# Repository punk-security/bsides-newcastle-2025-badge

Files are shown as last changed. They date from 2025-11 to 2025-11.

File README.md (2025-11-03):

# bsides-newcastle-2025-badge
The space badge for BSIDES Newcastle 2025!

This badge is a bit like our other ones, such as Cheltenham 2024 which was also a morse code game.

For this one, we printed some signs out with the codes for the players and stuck them around the venue. We really wanted to do a more art focused badge, so we didnt try any new technical gimmicks. The satellite you see on the badge was traced using the Angel of the North, which is a northern landmark near Newcastle. All the signs we made are in the signs directory. The morse code guide is included here too, as manual.png and manual.psd

The badge was made using our standard approach. We design it first in Inkscape, then convert it to a PCB in AutoCAD Eagle, and then we turn it into a full colour silk screen PCB using JLCPCB EasyEDA. 

If you want to modify the design, we've uploaded all the files you need. EAGLE.brd and EAGLE.sch can be loaded into AutoCAD Eagle to modify the PCB. Or you can skip the step and import EASYEDA.epro into EasyEDA.

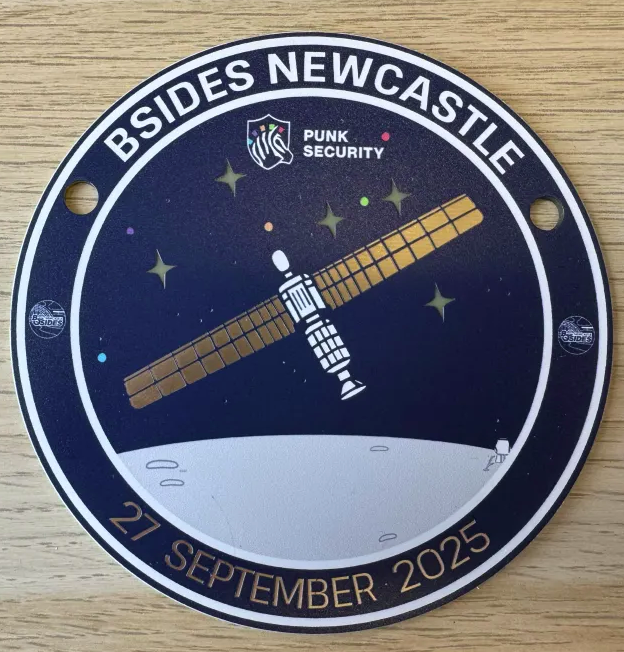
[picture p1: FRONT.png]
PCB Front

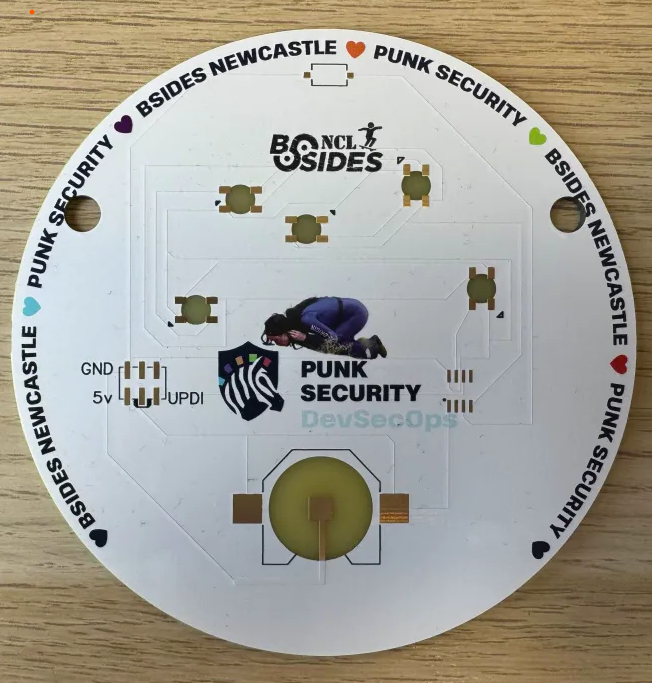
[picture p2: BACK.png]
PCB Back


## Bill Of Materials

You can see a parts list on DigiKey [here](https://www.digikey.co.uk/en/mylists/list/Z9CH9C1GM3)

Essentially its:

* ATTINY412 microcontroller 
* Button - any surface mount button fitting the footprint will work
* CR2032 battery clip - surface mount not through hole
* Neopixel 5050 addressable LED - Definitely get the right version of these

## Writing and flashing code!

We use [MegaTinyCore](https://github.com/SpenceKonde/megaTinyCore) for the arduino interface for ATTINY4x2 chips.

Dev and flashing is done within the Arduino IDE ( < v2 ) using a jtag2updi interface, as discussed [here](https://github.com/SpenceKonde/AVR-Guidance/blob/master/UPDI/jtag2updi.md)

We use [these little usb sticks](https://amzn.eu/d/c0lx0wG), with a 4.7k resistor soldered between the Tx and Rx lines.  

### Installing MegaTinyCore dependencies

This board package can be installed via the board manager in arduino. The boards manager URL is:

`http://drazzy.com/package_drazzy.com_index.json`

1. File -> Preferences, enter the above URL in "Additional Boards Manager URLs"
2. Tools -> Boards -> Boards Manager...
3. Wait while the list loads (takes longer than one would expect, and refreshes several times).
4. Select "megaTinyCore by Spence Konde" and click "Install". For best results, choose the most recent version.

### Setting up the IDE

1. Open the file **firmware.ino** in arduino
2. Select tools > Board > megaTinyCore > ATtiny412/402/212/202
3. Select tools > Chip > ATtiny412
4. Select tools > Clock > 16Mhz internal *(we get power issues otherwise)*
5. Select tools > Programmer > SerialUPDI SLOW
6. Select tools > Port > ( pick your COM port)

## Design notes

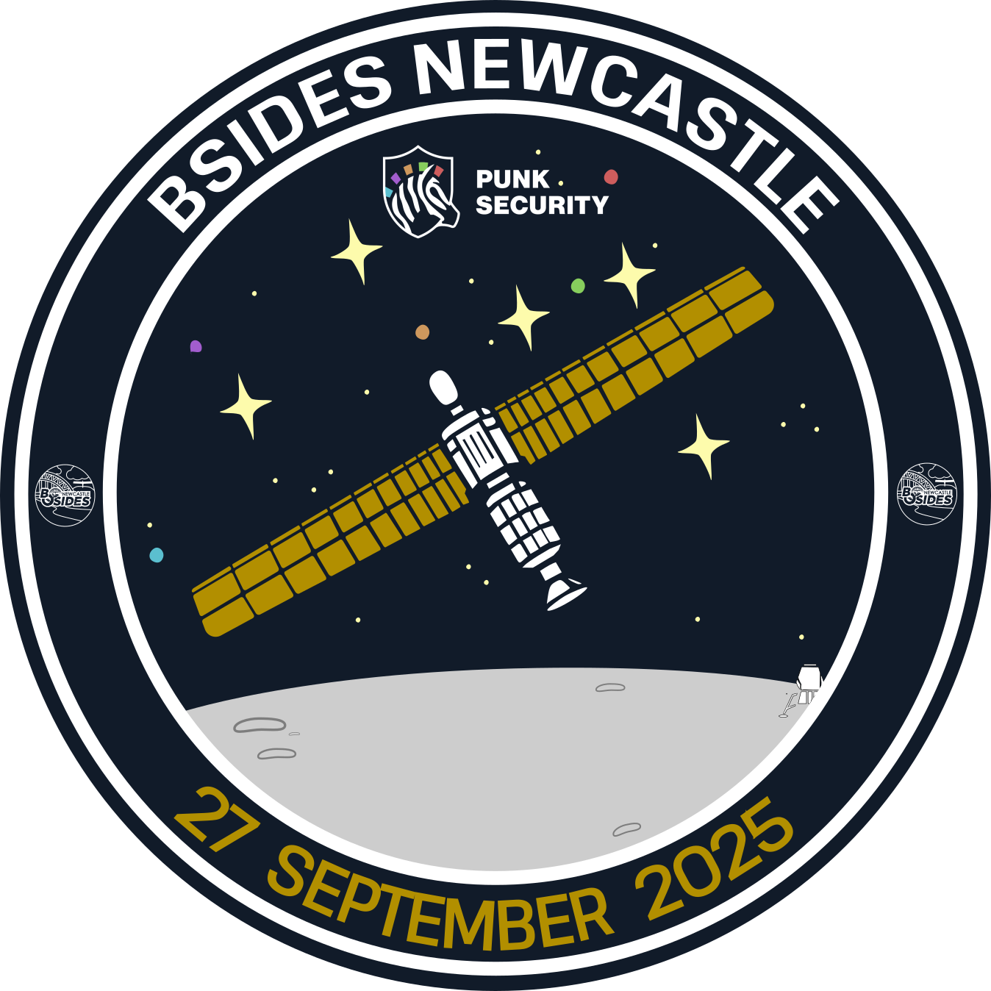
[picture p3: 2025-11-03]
bsdies_ncl.png

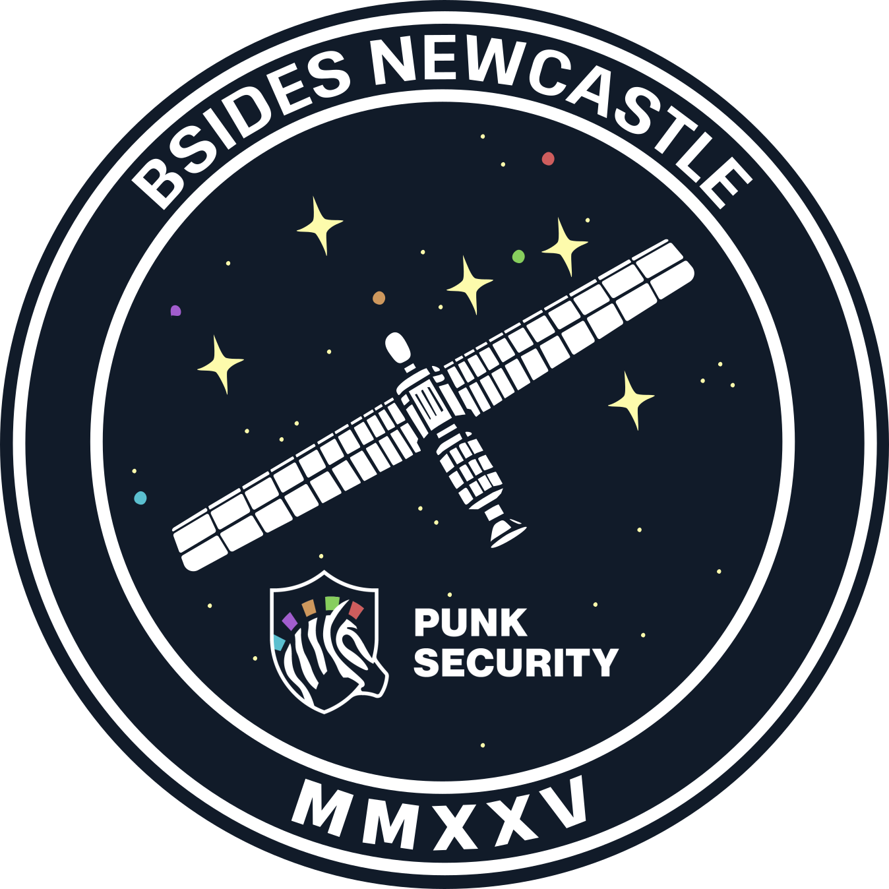
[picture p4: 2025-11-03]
bsdies_ncl_sticker.png

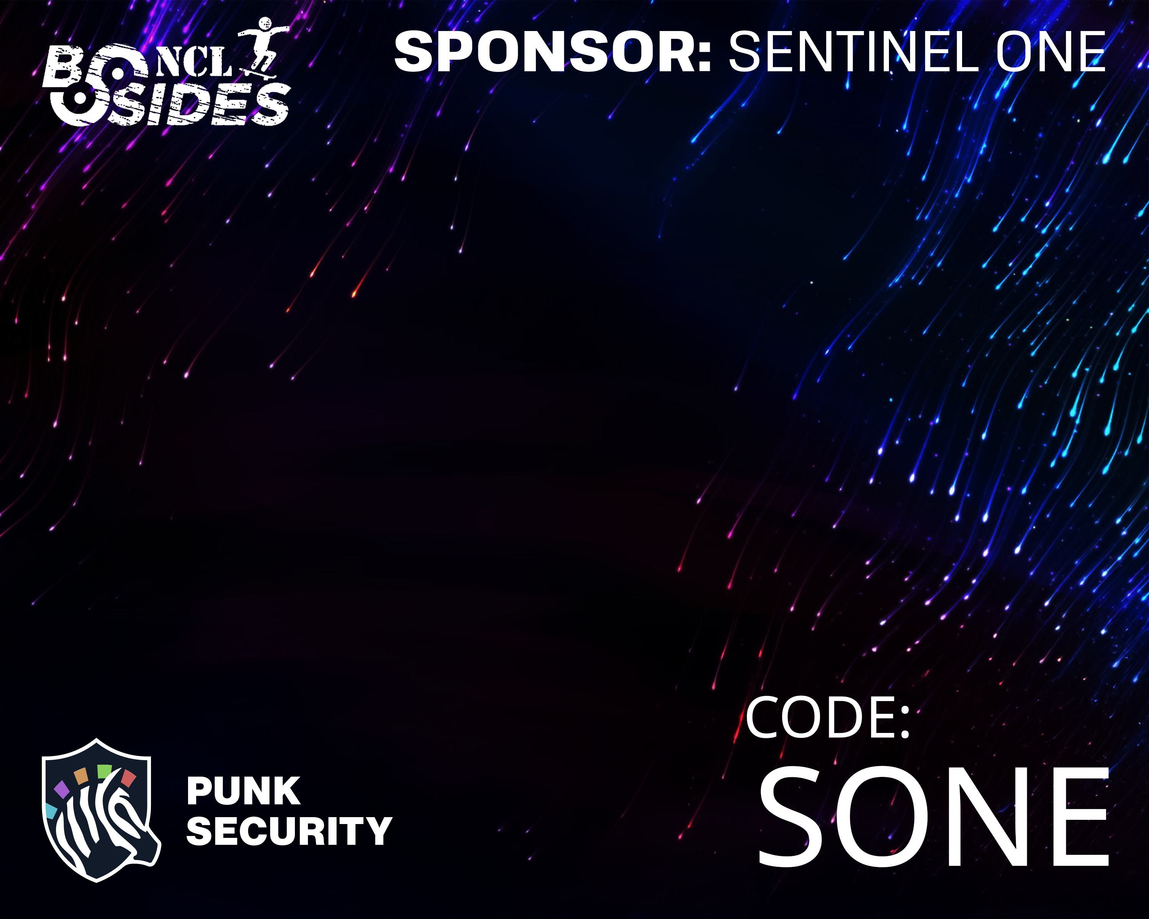
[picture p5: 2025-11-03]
signs/SONE.png

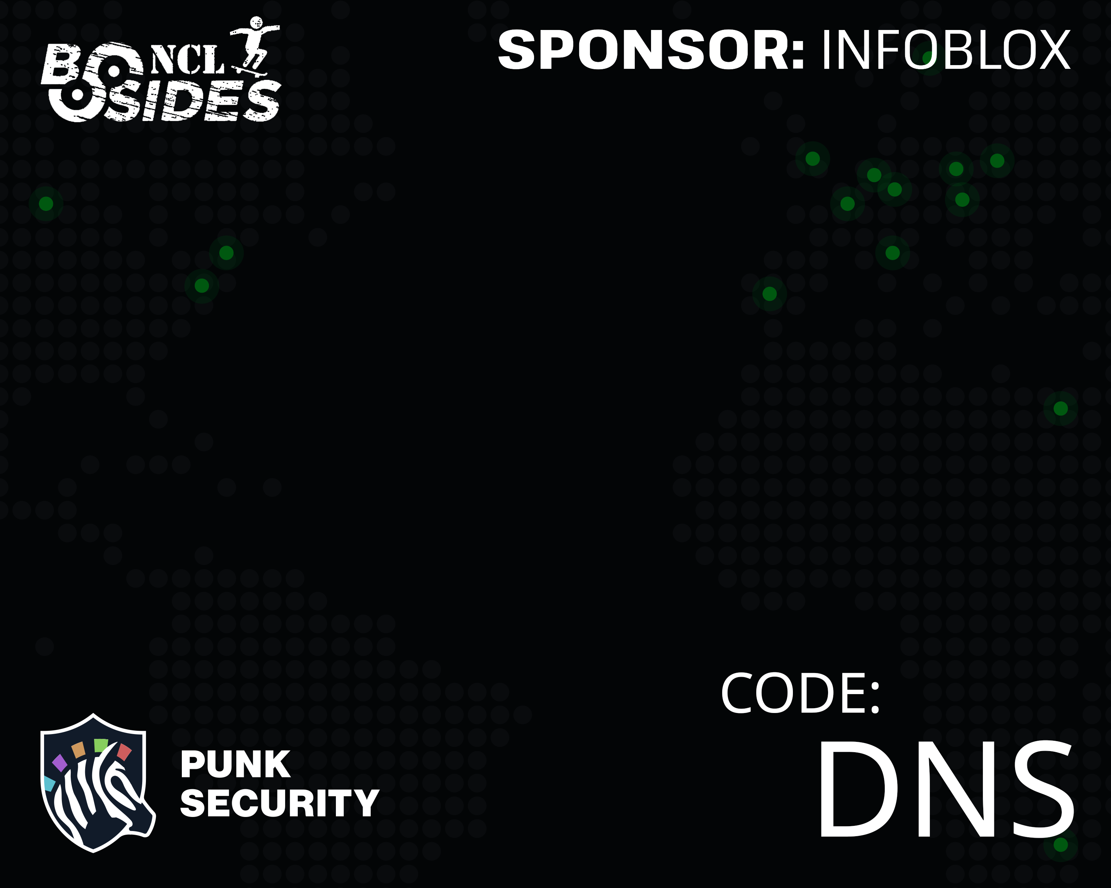
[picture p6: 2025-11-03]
signs/DNS.png

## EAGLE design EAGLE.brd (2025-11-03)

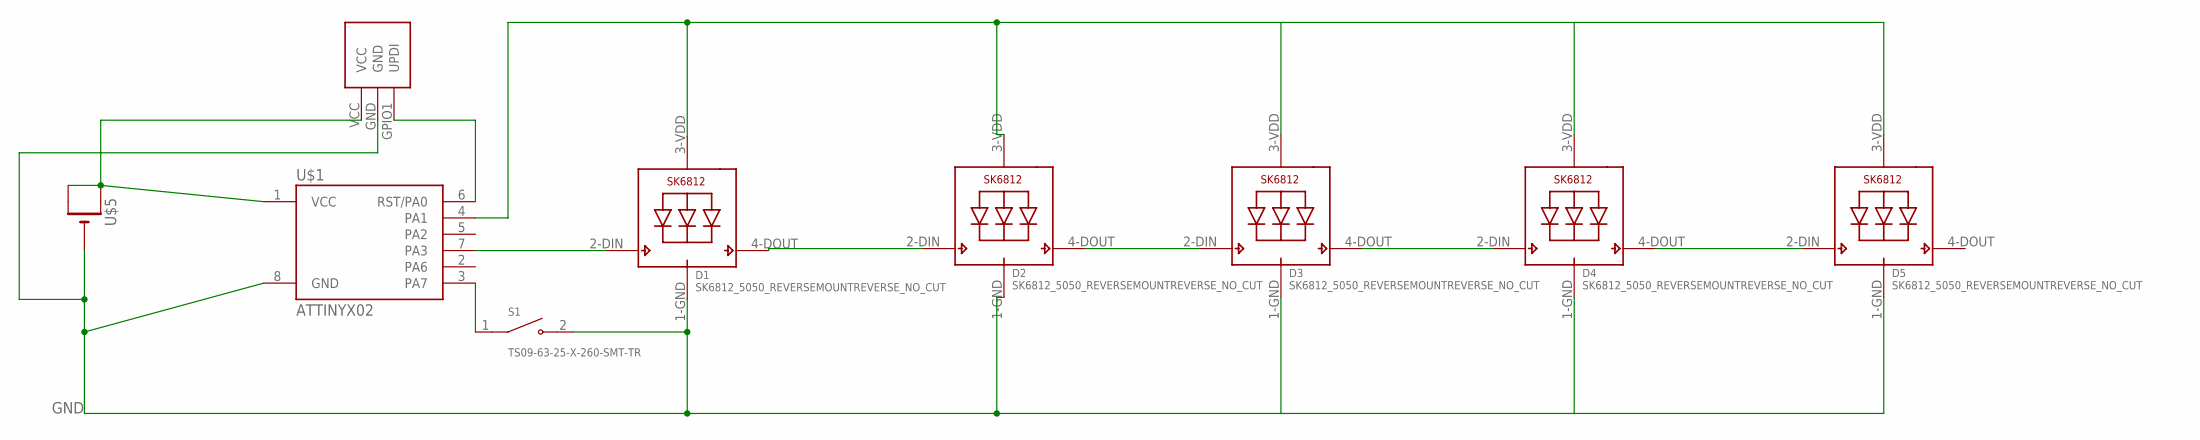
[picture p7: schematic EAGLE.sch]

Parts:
D1, D2, D3, D4, D5: SK6812_5050_REVERSEMOUNTREVERSE_NO_CUT; SK6812_REVERSE_NO_CUT
S1: TS09-63-25-X-260-SMT-TR; SW_TS09-63-25-X-260-SMT-TR
U$1: ATTINYX02; SOIC08_JEDEC_150MIL
U$2: SAO; SAO_SMD
U$5: CR2032SMT; CR2032-SMD

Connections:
GND: D1.1-GND (GND), D2.1-GND (GND), D3.1-GND (GND), D4.1-GND (GND), D5.1-GND (GND), S1.2, U$1.8 (GND), U$2.GND, U$5.-
unnamed: D1.4-DOUT (DO), D2.2-DIN (DI)
unnamed: D1.2-DIN (DI), U$1.7 (PA3)
unnamed: D3.4-DOUT (DO), D4.2-DIN (DI)
unnamed: D2.4-DOUT (DO), D3.2-DIN (DI)
unnamed: S1.1, U$1.3 (PA7)
unnamed: D4.4-DOUT (DO), D5.2-DIN (DI)
unnamed: U$1.6 (RST/PA0), U$2.GPIO1 (UPDI)
VCC1: U$1.1 (VCC), U$2.VCC, U$5.+$1 (+), U$5.+$2 (+1)
VDD1: D1.3-VDD (VDD), D2.3-VDD (VDD), D3.3-VDD (VDD), D4.3-VDD (VDD), D5.3-VDD (VDD), U$1.4 (PA1)

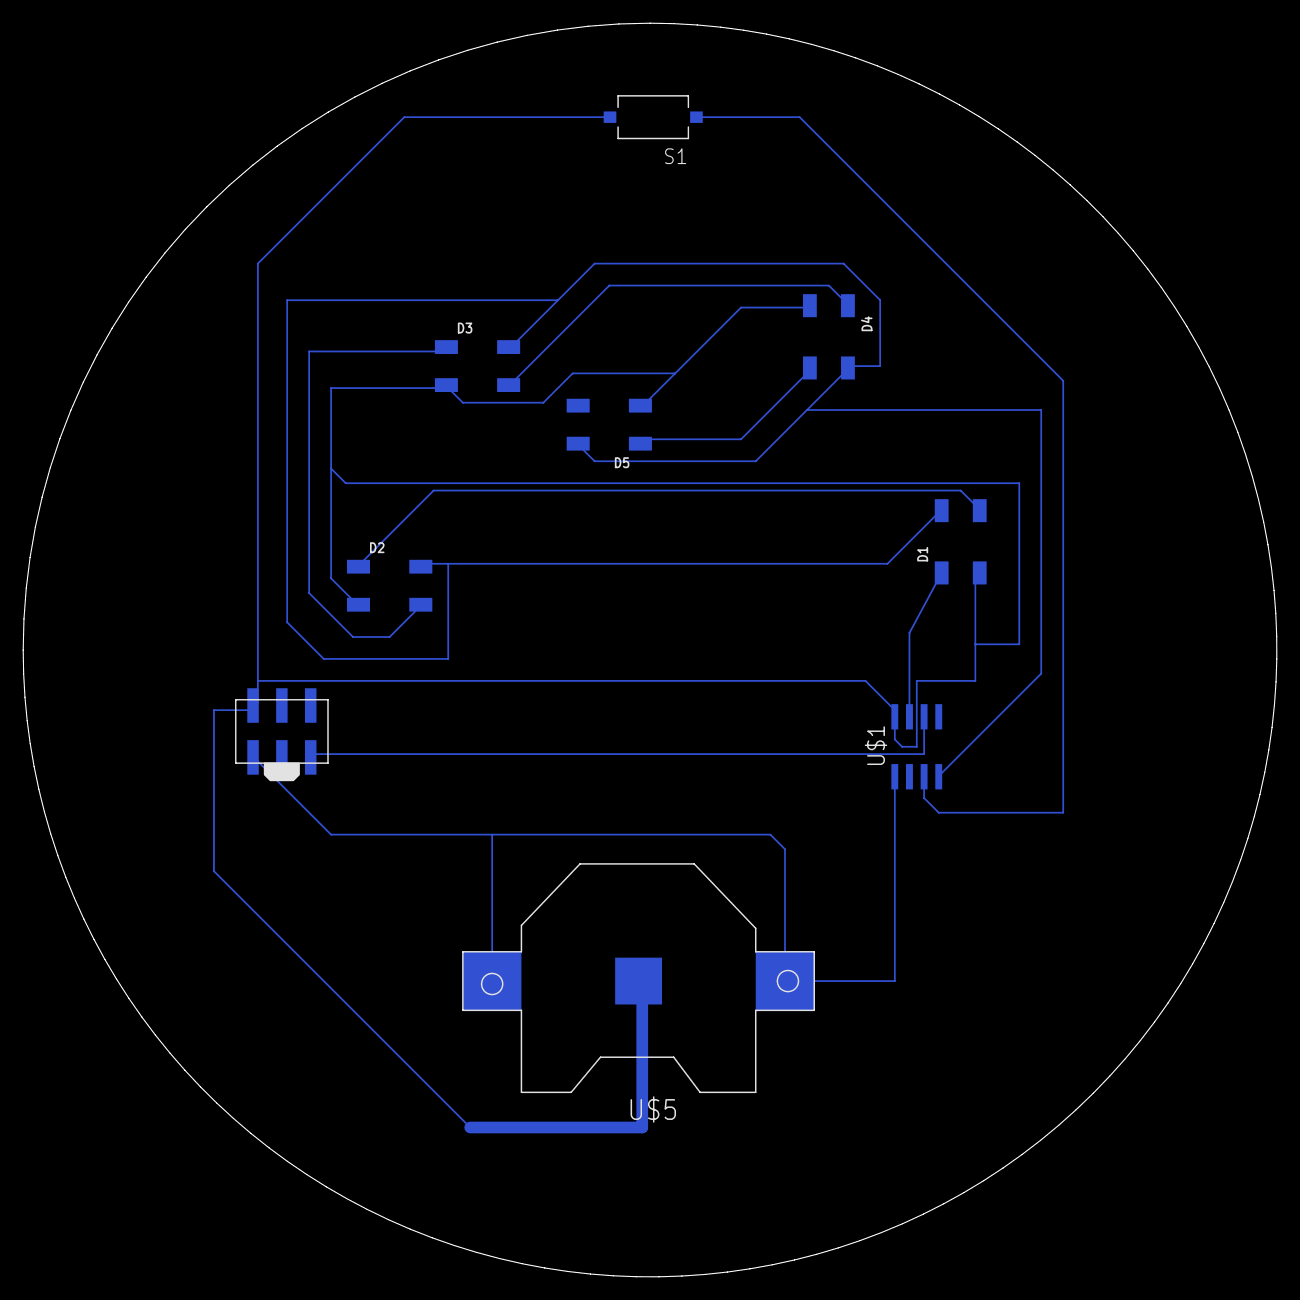
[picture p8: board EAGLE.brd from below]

Board: 2 copper layers, 108.7 x 108.7 mm, 9 parts (9 on the bottom side), 10 nets.

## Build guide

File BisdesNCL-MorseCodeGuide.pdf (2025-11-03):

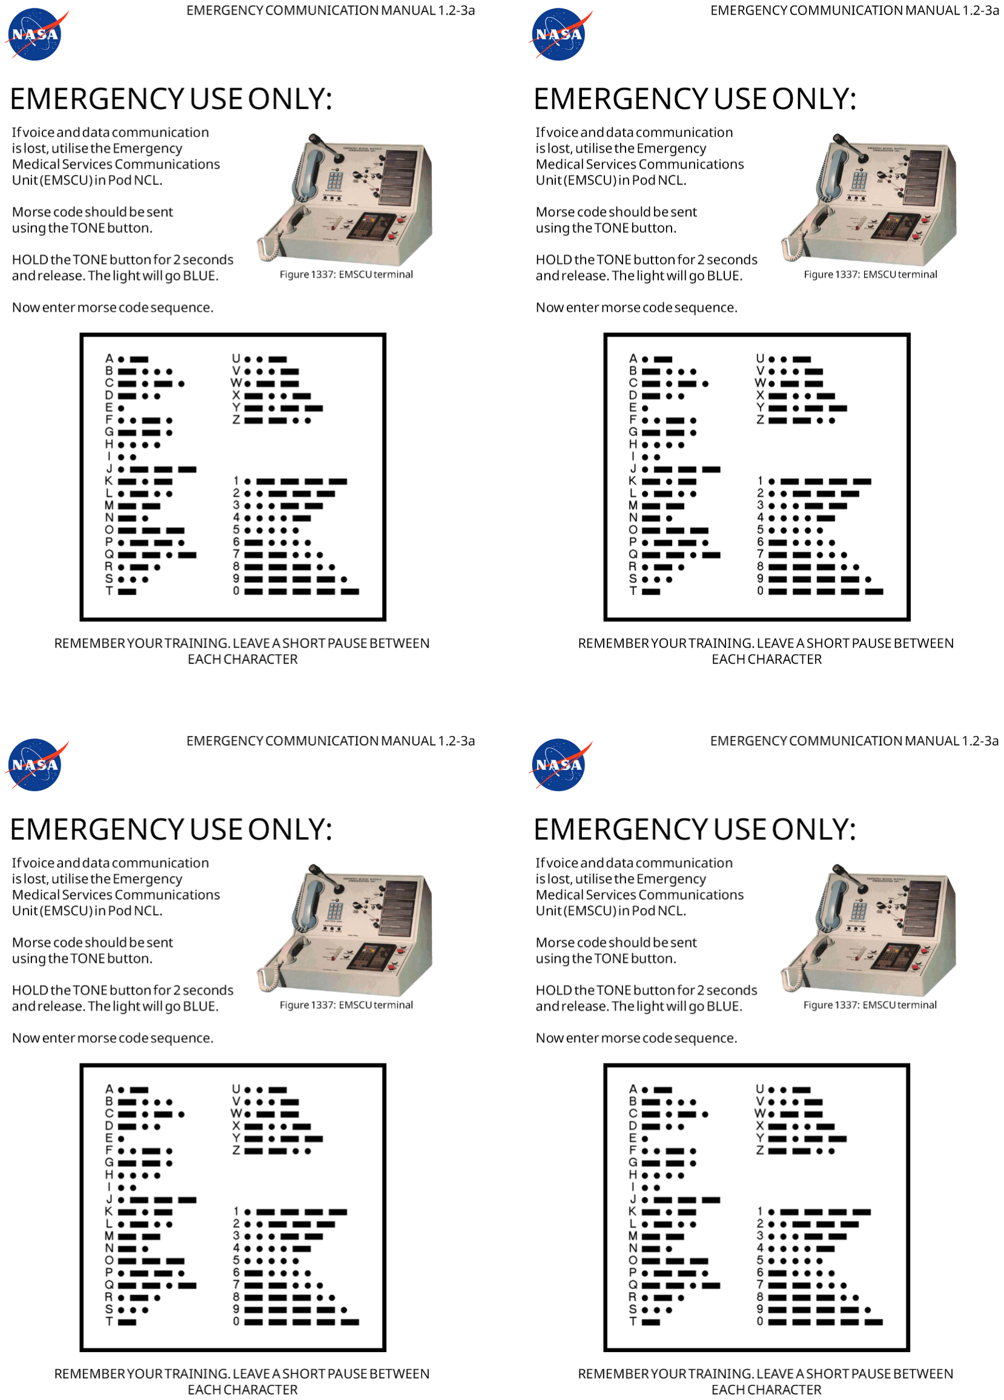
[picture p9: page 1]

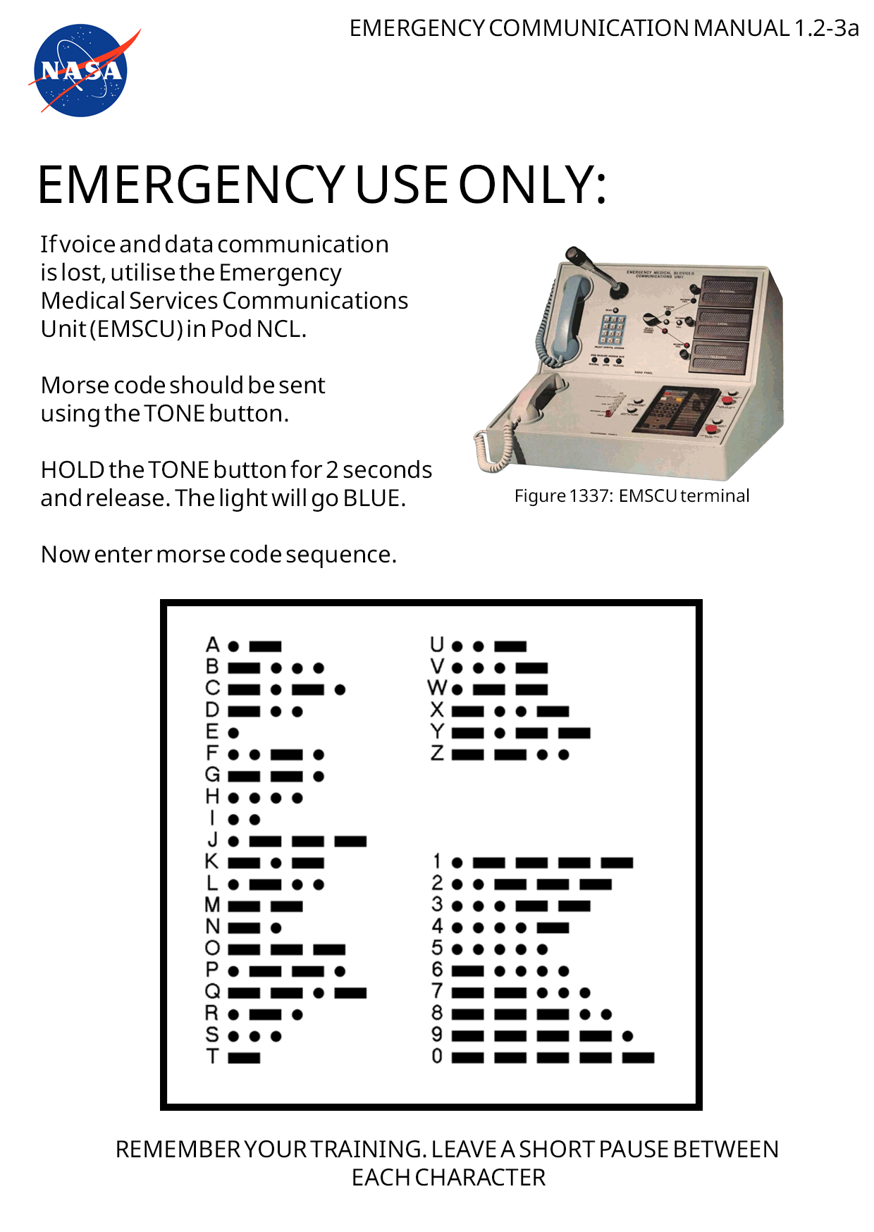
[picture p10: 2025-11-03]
manual.png

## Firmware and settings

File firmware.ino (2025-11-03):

// 16Mhz, disable millis timer

// MORSE CODE CODES
/*
 *
 * MORSE CODE is between 1 and 5 pulses long
 *
 * To store this in one byte we have the length, (3 bits) and each position as either 0 (dot) or 1 (dash)
 * i.e.
 * A = 010 01 000
 * B = 100 1000 0
 * C = 100 1010 0
 */

#include <avr/io.h>-
#include <avr/pgmspace.h>
#include <EEPROM.h>

//Definitions

# define WAKE_TIME_MS 2400000

//COLOURS
#define OFF 0,0,0

#define RED 30,0,0
#define GREEN 0,8,0
#define BLUE 0,0,30
#define ORANGE 20,8,0
#define PINK 6,0,4
#define PURPLE 6,0,15
#define OLIVE 2,2,0
#define YELLOW 18,12,0
#define YELLOWGREEN 20,30,20

// LED Order

#define LED0 0
#define LED1 3
#define LED2 4
#define LED3 2
#define LED4 1

const uint8_t p[] = {LED0,LED1,LED2,LED3,LED4};

// A .-
#define m_A B01001000
// B -...
#define m_B B10010000
// C -.-.
#define m_C B10010100
// D -..
#define m_D B01110000
// E .
#define m_E B00100000
// F ..-.
#define m_F B10000100
// G --.
#define m_G B01111000
// H ....
#define m_H B10000000
// I ..
#define m_I B01000000
// J .---
#define m_J B10001110
// K -.-
#define m_K B01110100
// L .-..
#define m_L B10001000
// M --
#define m_M B01011000
// N -.
#define m_N B01010000
// O ---
#define m_O B01111100
// P .--.
#define m_P B10001100
// Q --.-
#define m_Q B10011010
// R .-.
#define m_R B01101000
// S ...
#define m_S B01100000
// T -
#define m_T B00110000
// U ..-
#define m_U B01100100
// V ...-
#define m_V B10000010
// W .--
#define m_W B01101100
// X -..-
#define m_X B10010010
// Y -.--
#define m_Y B10010110
// Z --..
#define m_Z B10011000
// 1 .----
#define m_1 B10101111
// 2 ..---
#define m_2 B10100111
// 3 ...--
#define m_3 B10100011
// 4 ....-
#define m_4 B10100001
// 5 .....
#define m_5 B10100000
// 6 -....
#define m_6 B10110000
// 7 --...
#define m_7 B10111000
// 8 ---..
#define m_8 B10111100
// 9 ----.
#define m_9 B10111110
// 0 -----
#define m_0 B10111111

// We need to time the high periods, and work out if we are a dot, dash or have finished the char / word
#define MORSE_CODE_PIN PIN_PA7
#define MORSE_CODE_MAX_DOT_MS 400 // LOW - Any longer than this and its a dash
#define MORCE_CODE_MAX_DASH_MS 2000 // LOW - Any longer than this and its an error
#define MORSE_CODE_MAX_CHAR_INTERVAL_MS 800 // LOW - Any longer than this and we end the character
#define MORSE_CODE_MAX_WORD_INTERVAL_MS MORSE_CODE_MAX_CHAR_INTERVAL_MS * 3 // LOW - Any longer than this and we end the secret code

#define MORSE_CODE_CHAR_ERROR 0

#define MORSE_CODE_MAX_HIGH_MS MORCE_CODE_MAX_DASH_MS


uint16_t time_pin_low(uint16_t max_ms)
{
  // blocking for up to max_ms
  if (digitalRead(MORSE_CODE_PIN) == HIGH)
  {
    return(0);
  }
  mini_sleep();
  mini_sleep();
  //delay(36); //debounce-
  uint16_t t = 36;
  while(digitalRead(MORSE_CODE_PIN) == LOW)
  {
    mini_sleep();
    //delay(5);
    // t = t + 5;
    t = t + 15;
    if ( t > max_ms )
      return(max_ms);
  }
  return(t);
}

uint16_t time_pin_high(uint16_t max_ms)
{
  // blocking for up to max_ms
  if (digitalRead(MORSE_CODE_PIN) == LOW)
  {
    return(0);
  }
  delay(50); //debounce-
  uint16_t t = 50;
  while(digitalRead(MORSE_CODE_PIN) == HIGH)
  {
    delay(5);
    t = t + 5;
    if ( t > max_ms )
      return(max_ms);
  }
  return(t);
}

byte read_morse_char()
{
  // this function blocks
  byte code = B0000000;
  uint16_t lastPulseLength;
  uint8_t pos = 0;
  while(pos < 5)
  {
    lastPulseLength = time_pin_low(MORCE_CODE_MAX_DASH_MS);
    if (lastPulseLength == 0 || lastPulseLength == MORCE_CODE_MAX_DASH_MS) {return MORSE_CODE_CHAR_ERROR;} // return null byte on error
    if (lastPulseLength < MORSE_CODE_MAX_DOT_MS)
    {
      // set dot as the LOW was less than a dash
      // dots are zero so nothing to set but bump the pos
      pos++;
    }
    else
    {
      // set dash
      bitSet(code, (4 - pos)); // bits in byte are 76543210, we start at 4 and move right
      pos++;
    }
    // At this point we have read the low dash or dot but we dont know if its the end of the char.
    lastPulseLength = time_pin_high(MORSE_CODE_MAX_CHAR_INTERVAL_MS);
    if (lastPulseLength == MORSE_CODE_MAX_CHAR_INTERVAL_MS)
    {
      // The low time was higher than the intra-character spacing max so must end this character
     code |= pos << 5; // set the pos bits
     return(code); 
    }
  }
    // We have already got all 5 dots/dashes, cant RX any more
    return MORSE_CODE_CHAR_ERROR; //return Error
}

#define MAX_SECRET_CODE_LENGTH 4

void read_morse_word(char code[])
{
  uint8_t pos = 0;
  pos = 0;
  byte lastChar;
  int8_t lastPulseLength;
  while(pos < MAX_SECRET_CODE_LENGTH)
  {
    lastChar = read_morse_char();
    if (lastChar == MORSE_CODE_CHAR_ERROR)
      return "";
    // We should still be HIGH here - we left the function because the wait was longer than the intra char interval
    code[pos] = lastChar;
    pos++;
    // Should we end the string early or capture the next character?
    if (time_pin_high(MORSE_CODE_MAX_CHAR_INTERVAL_MS) == MORSE_CODE_MAX_CHAR_INTERVAL_MS)
    {
      // The char interval has already passed inside the read_morse_char func.
      // If we go that length AGAIN, the code is over
      // i.e.  CHAR INT = 1s, WORD INT = 2s, 1s has elapsed so wait up to 1s for the next LOW to start
      return;
    }
  }
  // At MAX code length, so return
  return;
}

#include <tinyNeoPixel_Static.h>
#define NUMLEDS 6
byte pixels[NUMLEDS * 3];
tinyNeoPixel strip = tinyNeoPixel(NUMLEDS, PIN_PA3, NEO_GRB, pixels);





void setAllPixels(int r, int g, int b, bool show = false)
{
  for (int i = 0; i < NUMLEDS; i++) 
  {
    strip.setPixelColor(i,r,g,b);
  }
  if(show)
    strip.show();
}

int police(int x)
{
  setAllPixels(255,0,0);
  if( x & 1)
  {
    strip.setPixelColor(LED1,0,0,255);
    strip.setPixelColor(LED3,0,0,255);
  }
  else
  {
    strip.setPixelColor(LED0,BLUE);
    strip.setPixelColor(LED2,BLUE);
    strip.setPixelColor(LED4,BLUE);
  }
  strip.show();
  return 200;
}



int chase(int x, uint8_t r,uint8_t g, uint8_t b)
{
  strip.setPixelColor((x - 1) % 5,OFF); // turn last pixel off
  strip.setPixelColor((x % 5),r,g,b); // set current pixel
  strip.show();
  return 200;
}

int pumpkin(int x)
{
  chase(x+1,2,1,0);
  chase(x,ORANGE);
  chase(x-1,2,1,0);
  return 500;
}

int sone(int x)
{
  setAllPixels(PURPLE);
  if(x % 2 == 0)
  {
    strip.setPixelColor(LED0,20,20,20);
    strip.setPixelColor(LED3,20,20,20);
  }
  else
  {
    strip.setPixelColor(LED1,20,20,20);
    strip.setPixelColor(LED2,20,20,20);
    strip.setPixelColor(LED4,20,20,20);
  }
  strip.show();
  return 300;
}

int pink(int x, int r, int g, int b, int r2, int g2, int b2)
{
  if(x % 2 == 0)
  {
    strip.setPixelColor(LED0,r,g,b);
    strip.setPixelColor(LED1,r2,g2,b2);
    strip.setPixelColor(LED2,r,g,b);
    strip.setPixelColor(LED3,r2,g2,b2);
    strip.setPixelColor(LED4,r,g,b);
  }
  else
  {
    strip.setPixelColor(LED0,r2,g2,b2);
    strip.setPixelColor(LED1,r,g,b);
    strip.setPixelColor(LED2,r2,g2,b2);
    strip.setPixelColor(LED3,r,g,b);
    strip.setPixelColor(LED4,r2,g2,b2);
  }
  strip.show();
  return 100;
}

int fill(int x, int r, int g, int b)
{
  int step = x % 10;
  switch(step)
  {
    case 0:
      setAllPixels(OFF);
      break;
    case 1 ... 6:
      strip.setPixelColor(p[step - 1], r,g,b);
      break;
    default:
      break;
  }
  strip.show();
  return 100;
}

#include <avr/sleep.h>

void sleep()
{
  set_sleep_mode(SLEEP_MODE_PWR_DOWN);
  PORTA.PIN7CTRL = PORT_PULLUPEN_bm | PORT_ISC_LEVEL_gc; // enable pullup and interrupt
  digitalWrite(PIN_PA1, LOW); // turn off LED power rail
  sleep_enable();
  sleep_cpu();
  // sleep resumes here
  PORTA.PIN7CTRL = PORT_PULLUPEN_bm; // renable pullup but no interrupt
  digitalWrite(PIN_PA1, HIGH);  // turn on LED power rail
}

RTC_PERIOD_enum period = RTC_PERIOD_CYC16_gc;

void RTC_init()
{
  /* Initialize RTC: */
  while (RTC.STATUS > 0)
  {
    ;                                   /* Wait for all register to be synchronized */
  }
  RTC.CLKSEL = RTC_CLKSEL_INT1K_gc;    /* 1kHz Internal Ultra-Low-Power Oscillator (OSCULP32K) */
}

void mini_sleep()
{
  RTC.PITINTCTRL = RTC_PI_bm;  // Enable RTC interrupt
  RTC.PITCTRLA = period | RTC_PITEN_bm; // Set timer to 2s
  set_sleep_mode(SLEEP_MODE_PWR_DOWN);
  sleep_enable();
  sleep_cpu();
  RTC.PITINTCTRL = ~(RTC_PI_bm); // Disable RTC interrupt
}

ISR(RTC_PIT_vect)
{
  RTC.PITINTFLAGS = RTC_PI_bm;  // Clear RTC interrupt flag otherwise keep coming back here
}

ISR(PORTA_PORT_vect) {
  PORTA.INTFLAGS = PORT_INT7_bm; // Clear Pin 7 interrupt flag otherwise keep coming back here
}

uint8_t state;

void setup()
{
  // Power save
  // http://www.technoblogy.com/show?2RA3
  // https://github.com/SpenceKonde/megaTinyCore/blob/master/megaavr/extras/PowerSave.md
  ADC0.CTRLA &= ~ADC_ENABLE_bm; // Disable ADC
  pinMode(PIN_PA1, OUTPUT);
  pinMode(PIN_PA2, OUTPUT);
  pinMode(PIN_PA6, OUTPUT);
  // UPDI does not need setting (PA0)

  // Pin setup
  pinMode(PIN_PA3, OUTPUT);
  pinMode(PIN_PA7, INPUT_PULLUP);
  digitalWrite(PIN_PA1, HIGH);

  
  state = EEPROM.read(0);
  RTC_init();
}

void flash_morse(byte b)
{
  for(int8_t i = 7; i > -1; i--)
  {
    setAllPixels(0,0,0,true);
    delay(100);
    if(b & (1 << i))
    {
      setAllPixels(5,0,0,true);
    }
    else
    {
      setAllPixels(0,0,5,true);
    }
    delay(500);
  }
}

void flash_morse_word(char *s)
{
  for(int i = 0; i < MAX_SECRET_CODE_LENGTH; i++)
  {
    if(s[i] == 0)
      return;   
    flash_morse(s[i]);
    setAllPixels(0,5,0,true);
    delay(300);
  }
  return;
}

void t_morse()
{
  char m[MAX_SECRET_CODE_LENGTH] = {0};
  setAllPixels(0,0,0,true);
  while(digitalRead(MORSE_CODE_PIN) == HIGH)
  {
    delay(10);
  }
  read_morse_word(m);
  flash_morse_word(m);
}

bool c_array(char array_1[],char array_2[])
{
  for (int i = 0;  i < MAX_SECRET_CODE_LENGTH; i++)
  {
  if( array_1[i] != array_2[i] ) 
    return false;
  }
  return true;
}

uint8_t success(uint8_t mode)
{
    EEPROM.update(0, state);
    setAllPixels(0,5,0,true);
    delay(500);
    return mode;
}

uint8_t fail(uint8_t mode)
{
    setAllPixels(5,0,0,true);
    delay(500);
    return mode;
}

uint8_t c_morse(uint8_t mode)
{
  // SECRET CODES
  char secret1[MAX_SECRET_CODE_LENGTH] = {m_S, m_A, m_G, m_E}; // GREEN
  char secret2[MAX_SECRET_CODE_LENGTH] = {m_S, m_O, m_S, 0}; // POLICE
  char secret3[MAX_SECRET_CODE_LENGTH] = {m_1, m_9, m_5, m_7};  // SPUTNIK
  char secret4[MAX_SECRET_CODE_LENGTH] = {m_5, m_0, m_4, m_B}; // PINK
  char secret5[MAX_SECRET_CODE_LENGTH] = {m_D, m_N, m_S, 0};  // INFOBLOX
  char secret6[MAX_SECRET_CODE_LENGTH] = {m_N, m_A, m_S, m_A}; // RED
  char secret7[MAX_SECRET_CODE_LENGTH] = {m_P, m_U, m_N, m_K}; // PUNK
  char secret8[MAX_SECRET_CODE_LENGTH] = {m_S, m_O, m_N, m_E}; // SENTINEL ONE
  char secret_reset[MAX_SECRET_CODE_LENGTH] = {m_R, m_S, m_T, 0};
  //char secret_all[MAX_SECRET_CODE_LENGTH] = {m_1, m_3, m_3, m_7};
  // BUFFER TO READ TO
  char i[MAX_SECRET_CODE_LENGTH] = {0};
  // SET PIXELS TO SHOW WE ARE READIING
  setAllPixels(0,0,5,true);
  // READ INPUT
  while(digitalRead(MORSE_CODE_PIN) == HIGH)
    delay(10);
  read_morse_word(i);
  //flash_morse_word(i);
  // TEST FOR A MATCH
  if (c_array(i, secret1))
  {
    state = state & ~B00000001;
    return success(3);
  }
  if (c_array(i, secret2))
  {
    state = state & ~B00000010;
    return success(4);
  }
  if (c_array(i, secret3))
  {
    state = state & ~B00000100;
    return success(5);
  }
  if (c_array(i, secret4))
  {
    state = state & ~B00001000;
    return success(6);
  }
  if (c_array(i, secret5))
  {
    state = state & ~B00010000;
    return success(7);
  }
  if (c_array(i, secret6))
  {
    state = state & ~B00100000;
    return success(8);
  }
  if (c_array(i, secret7))
  {
    state = state & ~B01000000;
    return success(9);
  }
  if (c_array(i, secret8))
  {
    state = state & ~B10000000;
    return success(10);
  }
  if (c_array(i, secret_reset))
  {
    state = B11111111;
    return success(0);
  }
//  if (c_array(i, secret_all))
//  {
//    state = B0;
//    return success(11);
//  }
  return fail(mode);
}




int fill_cycle(int x)
{
  int color_step = x % 60;
  switch (color_step)
  {
    case 1 ... 9:
      return fill(color_step,RED);    
    case 11 ... 19:
      return fill(color_step,GREEN);
    case 21 ... 29:
      return fill(color_step,ORANGE);
    case 31 ... 39:
      return fill(color_step,PURPLE);
    case 41 ... 49:
      return fill(color_step,BLUE);    
  }
  return 0;
}



int twinkle(uint8_t i){
  int b = i % 10;
  int l = i / 50;
  setAllPixels(OFF);
  strip.setPixelColor(l, 30 - b, 20 -b , 0);
  strip.show();
  return 50;
}



int loading(int x)
{
  
  int i = x % 25;
  setAllPixels(OFF);
  if ( i < 5 )
  {
    strip.setPixelColor(p[i],RED);
  }
  else if ( i < 9 )
  {
    strip.setPixelColor(1,RED);
    strip.setPixelColor(p[i-5],GREEN);
  }
  else if ( i < 12 )
  {
    strip.setPixelColor(1,RED);
    strip.setPixelColor(2,GREEN);
    strip.setPixelColor(p[i-9],ORANGE);
  }
  else if ( i < 15 )
  {
    strip.setPixelColor(1,RED);
    strip.setPixelColor(2,GREEN);
    strip.setPixelColor(4,ORANGE);
    strip.setPixelColor(p[i-13],PURPLE);
  }
  else
  {
    strip.setPixelColor(1,RED);
    strip.setPixelColor(2,GREEN);
    strip.setPixelColor(4,ORANGE);
    strip.setPixelColor(3,PURPLE);
    strip.setPixelColor(0,BLUE);
  }
  strip.show();
  return (100 + (i * 10));
}

int knightrider(uint8_t i, int r, int g, int b, int r2, int g2, int b2)
{
  setAllPixels(r2,g2,b2);
  int n = i % 12;
  if (n < 5)
  {
    strip.setPixelColor(p[n],r,g,b);
  }
  else if (n > 5)
  {
    strip.setPixelColor(p[10 - n],r,g,b);
  }
  strip.show();
  return 50;
}

int infoblox(int i)
{
  setAllPixels(20,20,20);
  strip.setPixelColor(LED1,0,i % 20,0);
  strip.show();
  return 20;
}

int sputnik(uint8_t i)
{
  
  int n = i % 4;
  if (n == 0)
  {
    setAllPixels(10,0,0);
    strip.setPixelColor(LED1,18,12,0);
  }
  else
  {
    setAllPixels(3,0,0);
    strip.setPixelColor(LED1,3,2,0);
  }
  strip.show();
  return 200;
}

uint8_t punkwork_led = 0;

uint8_t punkwork(int i)
{
  setAllPixels(OFF);
  uint8_t s = i % 10;
  uint8_t c = i / 10;
  uint8_t r = 0;
  uint8_t g = 0;
  uint8_t b = 0;
  if (c & 8) r = 10;
  if (c & 16) g = 10;
  if (c & 32) b = 10;
  if (c & 1) r = 30;
  if (c & 2) g = 30;
  if (c & 4) b = 30;
  if (c == 0) b=255;
  if (s == 0)
  {
    punkwork_led++;
    if (punkwork_led > 5) punkwork_led = 0;
    strip.setPixelColor(punkwork_led, 255, 255 , 255);
  }
  else if (s > 4);
  {
    strip.setPixelColor(punkwork_led, r / s, g / s, b / s);
  }
  strip.show();
  return 100;
}

uint16_t win(uint8_t i)
{
  strip.setPixelColor(LED0,0,0,7);
  strip.setPixelColor(LED1,2,0,5);
  strip.setPixelColor(LED2,3,2,0);
  strip.setPixelColor(LED3,0,3,0);
  strip.setPixelColor(LED4,3,0,0);
  const uint8_t code[] = { m_2, m_7, m_9, m_2, m_5 };
  const uint8_t code_lengths[] = { 5,5,5,5,5 };
  int n = i % 50;
  int b = n / 5;
  int s = n % 5;
  if (s == 0)
  {
    if (code_lengths[0] > b)
    strip.setPixelColor(LED0,BLUE);
    if (code_lengths[1] > b)
    strip.setPixelColor(LED1,PURPLE);
    if (code_lengths[2] > b)
    strip.setPixelColor(LED2,ORANGE);
    if (code_lengths[3] > b)
    strip.setPixelColor(LED3,GREEN);
    if (code_lengths[4] > b)
    strip.setPixelColor(LED4,RED);
  }
  if (s == 1 || s == 2)
  { 
    if ((code_lengths[0] > b) && (code[0] & (1 << 7 - (b + 3))))
    {
      strip.setPixelColor(LED0,BLUE);
    }
    if ((code_lengths[1] > b) && (code[1] & (1 << 7 - (b + 3))))
    {
      strip.setPixelColor(LED1,PURPLE);
    }
    if ((code_lengths[2] > b) && (code[2] & (1 << 7 - (b + 3))))
    {
      strip.setPixelColor(LED2,ORANGE);
    }
    if ((code_lengths[3] > b) && (code[3] & (1 << 7 - (b + 3))))
    {
      strip.setPixelColor(LED3,GREEN);
    }
    if ((code_lengths[4] > b) && (code[4] & (1 << 7 - (b + 3))))
    {
      strip.setPixelColor(LED4,RED);
    }
  }
  strip.show();
  return 200;
}

void loop()
{
  int mode = 0;
  uint16_t interval;
  uint16_t button_low_time = 0;
  uint32_t total_interval = 0;
  strip.begin();
  int i = 0;
  //state = 0;
  while(true)
  {
    if ( mode == 0 )
    {
      interval = twinkle(i);
    }
    else if ( mode == 1 )
    {
      interval = punkwork(i);
    }
    else if ( mode == 2 )
    {
      interval = pink(i, GREEN, PURPLE);
    }
    else if ( mode == 3 && !(state & B00000001 ))
    {
      interval = knightrider(i, GREEN, 0,1,0);
    }
    else if ( mode == 4 && !(state & B00000010 ))
    {
      interval = police(i);
    }
    else if ( mode == 5 && !(state & B00000100 ))
    {
      interval = sputnik(i);
    }
    else if ( mode == 6 && !(state & B00001000 ))
    {
      interval = pink(i, PINK, PURPLE);
    }
    else if ( mode == 7 && !(state & B00010000 ))
    {
      interval = infoblox(i);
    }
    else if ( mode == 8 && !(state & B00100000 ))
    {
      interval = knightrider(i, 255,0,0, 255,255,255);
    }
    else if ( mode == 9 && !(state & B01000000 ))
    {
      interval = loading(i);
    }
    else if ( mode == 10 && !(state & B10000000 ))
    {
      interval = sone(i);
    }
    else if ( mode == 11 && (state == 0 )) // FULL SET
    {
      interval = win(i);
    }
    else if (mode > 12)
    {
      mode = 0;
    }
    else
    {
      mode++;
      continue;
    }
    i++;
    // This section breaks down the sleep interval to catch button presses
    total_interval = total_interval + interval ;
    while(interval > 0)
    {
      mini_sleep();
      //delay(10);
      interval = interval - 10;
      button_low_time = time_pin_low(2000);
      if (button_low_time > 200)
      {
       /*
       * MAIN MENU
       * NO PRESS = CONTINUE
       * SHORT PRESS = CHANGE FLASHY MODE
       * LONG PRESS = ENTER MORSE CODE MODE
       */
       if (button_low_time > 1500)
        {
          setAllPixels(RED,true);
          while(digitalRead(MORSE_CODE_PIN) == LOW)
          {
            // WAIT FOR RELEASE BEFORE SLEEPING otherwise we wake back up!
            delay(5);
          }
          delay(50); //DEBOUNCE
          sleep();
        }
        else if (button_low_time > 600)
        {
          setAllPixels(BLUE,true);
          while(digitalRead(MORSE_CODE_PIN) == LOW)
            delay(10);
          mode = c_morse(mode);
        }
        else
        {
          mode = mode +1;
        }
        // reset timer
        i = 0;
        total_interval = 0;
      }

    }
    // At the end of each interval, see if we need to sleep
    if (total_interval > WAKE_TIME_MS)
    {
      total_interval = 0;
      i = 0;
      sleep();
    }
  }
}
